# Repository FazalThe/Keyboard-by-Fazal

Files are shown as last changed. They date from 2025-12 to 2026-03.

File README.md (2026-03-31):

# Custom Wireless Mechanical Keyboard (Pico W)
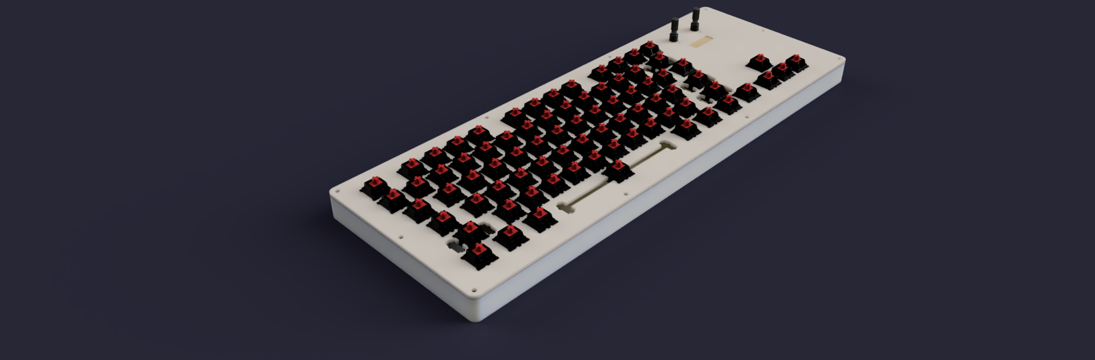
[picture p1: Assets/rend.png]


A custom-designed **wireless mechanical keyboard** built around the **Raspberry Pi Pico W**, featuring a hand-wired key matrix, rotary encoders, OLED display, rechargeable battery support, and a fully custom 3D-printed case.

The **Layout** is custome made by me

---

## 📸 Project Overview

### Top Plate
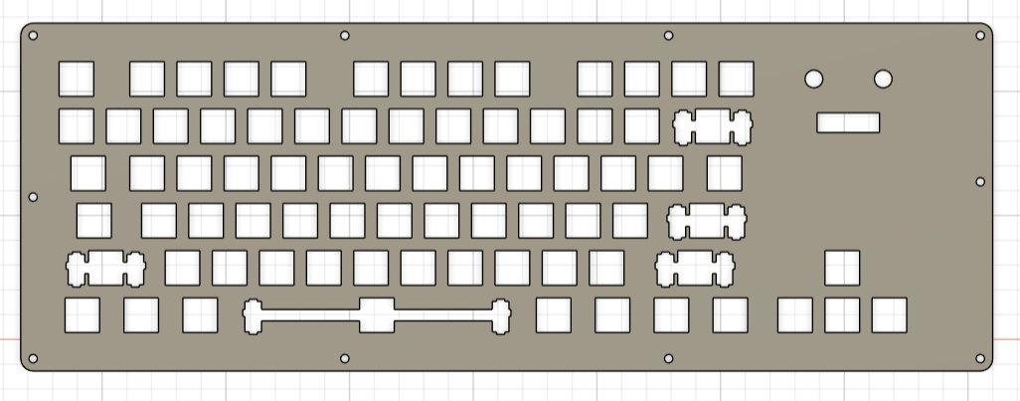
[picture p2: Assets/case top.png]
Case Top


### Case (Bottom Shell)
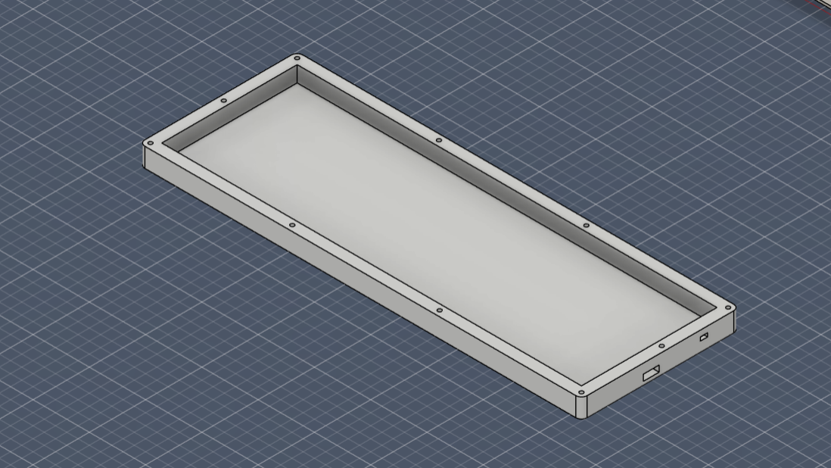
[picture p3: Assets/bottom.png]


### Key Layout
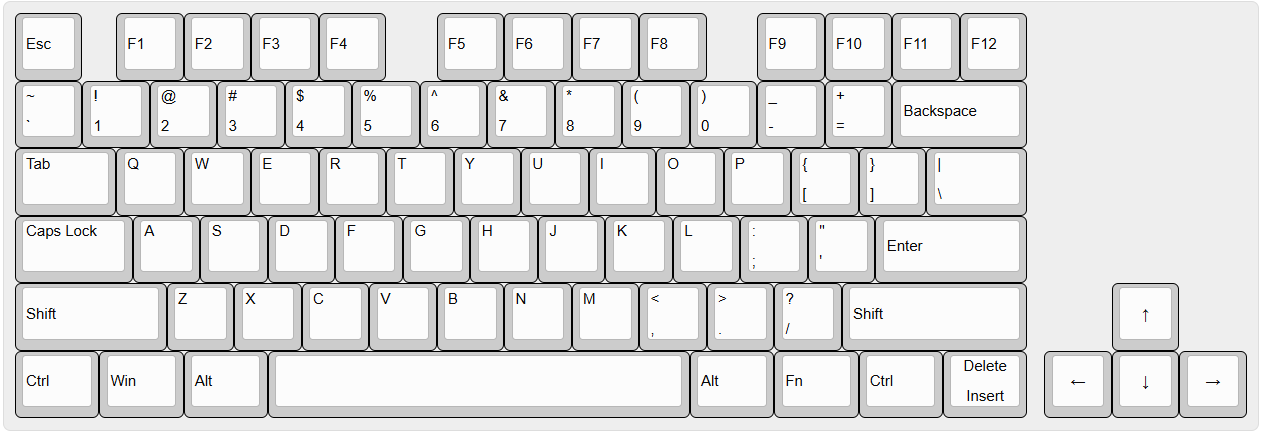
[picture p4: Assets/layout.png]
Layout


### Electrical Schematic
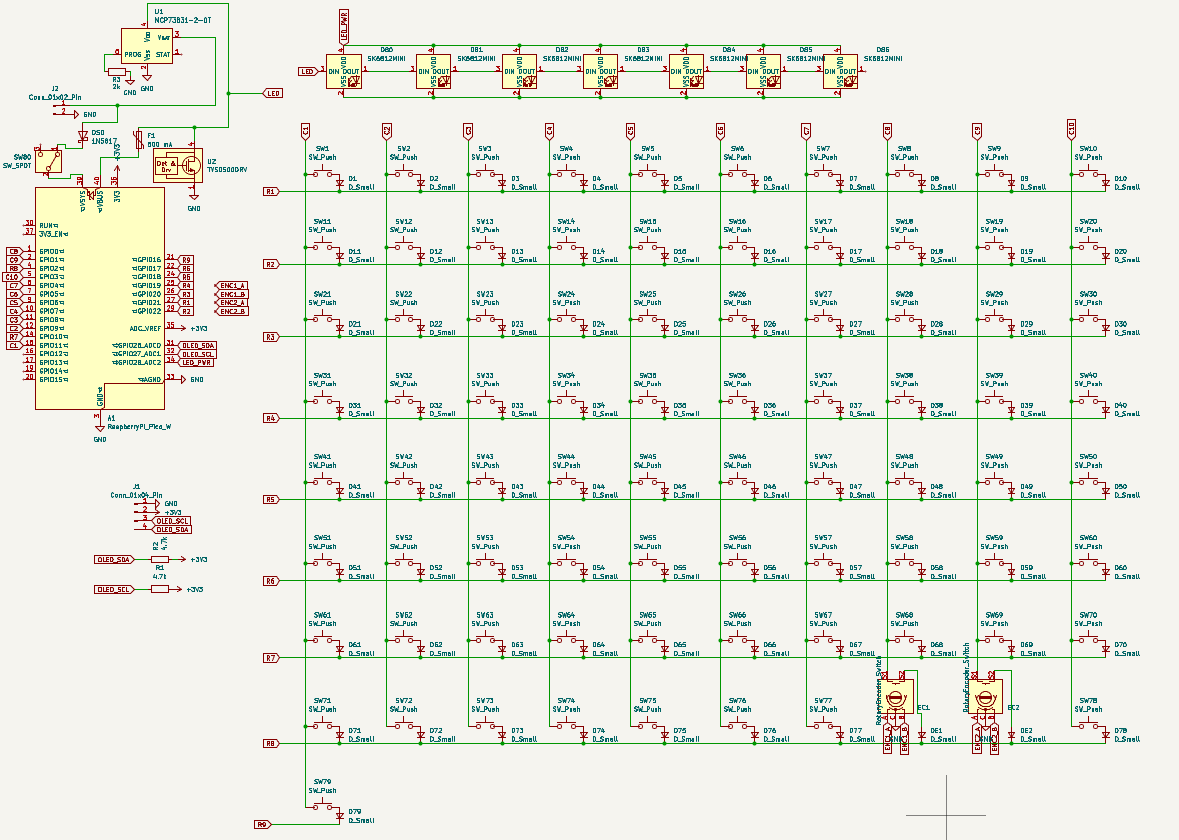
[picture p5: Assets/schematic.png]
Schematic


---

## 🧩 Bill of Materials 
### Core Electronics
- Raspberry Pi Pico W ×1  
- Mechanical key switches ×78  
- Keyboard diodes ×81  
- SK6812 MINI RGB LEDs ×7  
- Rotary encoders ×2  
- 0.91″ OLED display ×1  
- MCP73831 Li-ion charger ×1  
- TVS ESD protection IC ×1  
- Fuse (500 mA) ×1  
- Resistors (4.7 kΩ ×2, 2 kΩ ×1)  

### Power & Connectivity
- Protected Li-Po battery ×1  
- JST 2-pin battery connector ×1  
- USB connector / header ×1  
- SS12F15 slide switch ×1  

### Mechanical & Assembly
- MX keycaps ×78 (look layout for reference)  
- Rotary encoder caps ×2  
- Copper wire (for hand wiring)  
- Solder board / perfboard  
- M3 × 20 mm screws ×8  
- M3 heat-set inserts ×8  

---

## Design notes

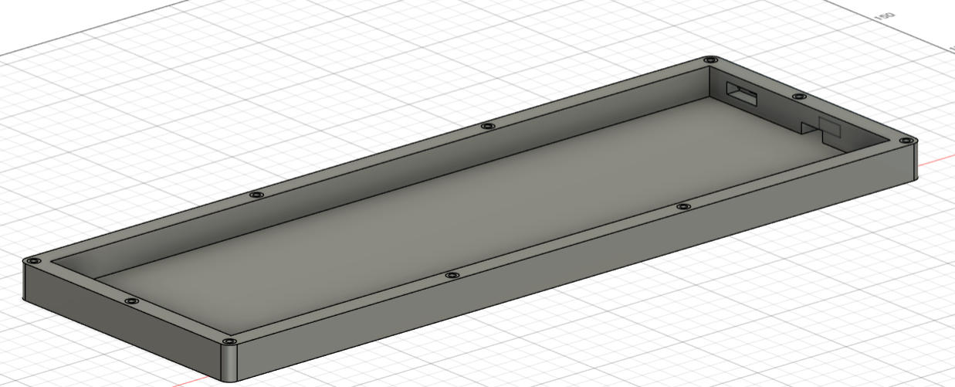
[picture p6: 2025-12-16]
Assets/case.png

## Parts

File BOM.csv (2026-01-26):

Product name | Product link | Price per piece (₹) | Quantity | Total price (₹) | Running total (₹)
Raspberry Pi Pico W | https://robu.in/product/raspberry-pi-pico-w/ | 614.00 | 1 | 614.00 | 614.00
2.2k Ohm 0.5W Metal Film Resistor (Pack of 50) | https://robu.in/product/2-2k-ohm-0-5w-metal-film-resistor-pack-of-50/ | 0.98 | 12 | 11.76 | 625.76
MCP73831T-2ACI/OT Li‑ion Charger IC (SOT‑23‑5) | https://robu.in/product/mcp73831t-2aci-ot-microchip-battery-charger-for-1-cell-of-li-ion-li-pol-battery-6v-input-4-2v-500ma-charge-sot-23-5/ | 89.00 | 1 | 89.00 | 714.76
1N5817 Schottky Rectifier 20V 1A DO‑41 | https://robu.in/product/1-month-warranty-1000/ | 9.00 | 5 | 45.00 | 759.76
0.91″ Monochrome OLED Display Panel Blue 14‑pin | https://robu.in/product/0-91-inch-monochrome-oled-display-panel-blue-14pin-2/ | 106.00 | 1 | 106.00 | 865.76
RXEF050 PTC Resettable Fuse 72V 500 mA (Radial) | https://robu.in/product/70-065-63-0-5a-siba-70-065-63-0-5a-fuse-cartridge-fast-acting-500-ma-500-v-6-3mm-x-32mm-1-4-x-1-1-4/ | 14.00 | 3 | 42.00 | 907.76
Electronic Spices 50Pcs 4.7KΩ 1/2W Resistors | https://www.amazon.in/gp/product/B0BDTXKCM3/ref=ox_sc_act_title_1 | 80.00 | 1 | 80.00 | 987.76
Rechargeable Li‑Po Battery 3.7V 800 mAh | https://www.amazon.in/gp/product/B0DTGSWDGP/ref=ox_sc_act_title_2 | 331.00 | 1 | 331.00 | 1,318.76
TRENDYNEST Plate Mounted Stabilizers 3×2U | https://www.amazon.in/gp/product/B0FRN1CF4Q/ref=ox_sc_act_title_3 | 862.00 | 1 | 862.00 | 2,180.76
Rpi shop M3×16mm CSK Allen Screws (10 pcs) | https://www.amazon.in/gp/product/B07XM7YMC9/ref=ox_sc_act_title_4 | 168.00 | 1 | 168.00 | 2,348.76
Electronic Spices 5 pcs 3×7 cm Universal PCB | https://www.amazon.in/gp/product/B0B8NGQQ9C/ref=ox_sc_act_title_5 | 172.00 | 1 | 172.00 | 2,520.76
100PCS A7 SMD Diode 1A 1000V SOD‑123 (1N4007) | https://www.amazon.in/gp/product/B09VK9966W/ref=ox_sc_act_title_6 | 100.00 | 1 | 100.00 | 2,620.76
CentIoT EC11 10K Rotary Encoder (2 pcs) | https://www.amazon.in/gp/product/B0888RWNM1/ref=ox_sc_act_title_7 | 172.00 | 1 | 172.00 | 2,792.76
Milk & Honey MOA PBT Keycaps | https://curiositycaps.in/products/honey-milk-moa-pbt-keycaps?variant=51748170924313 | 2,200 | 1 | 2,200 | 2,992.76

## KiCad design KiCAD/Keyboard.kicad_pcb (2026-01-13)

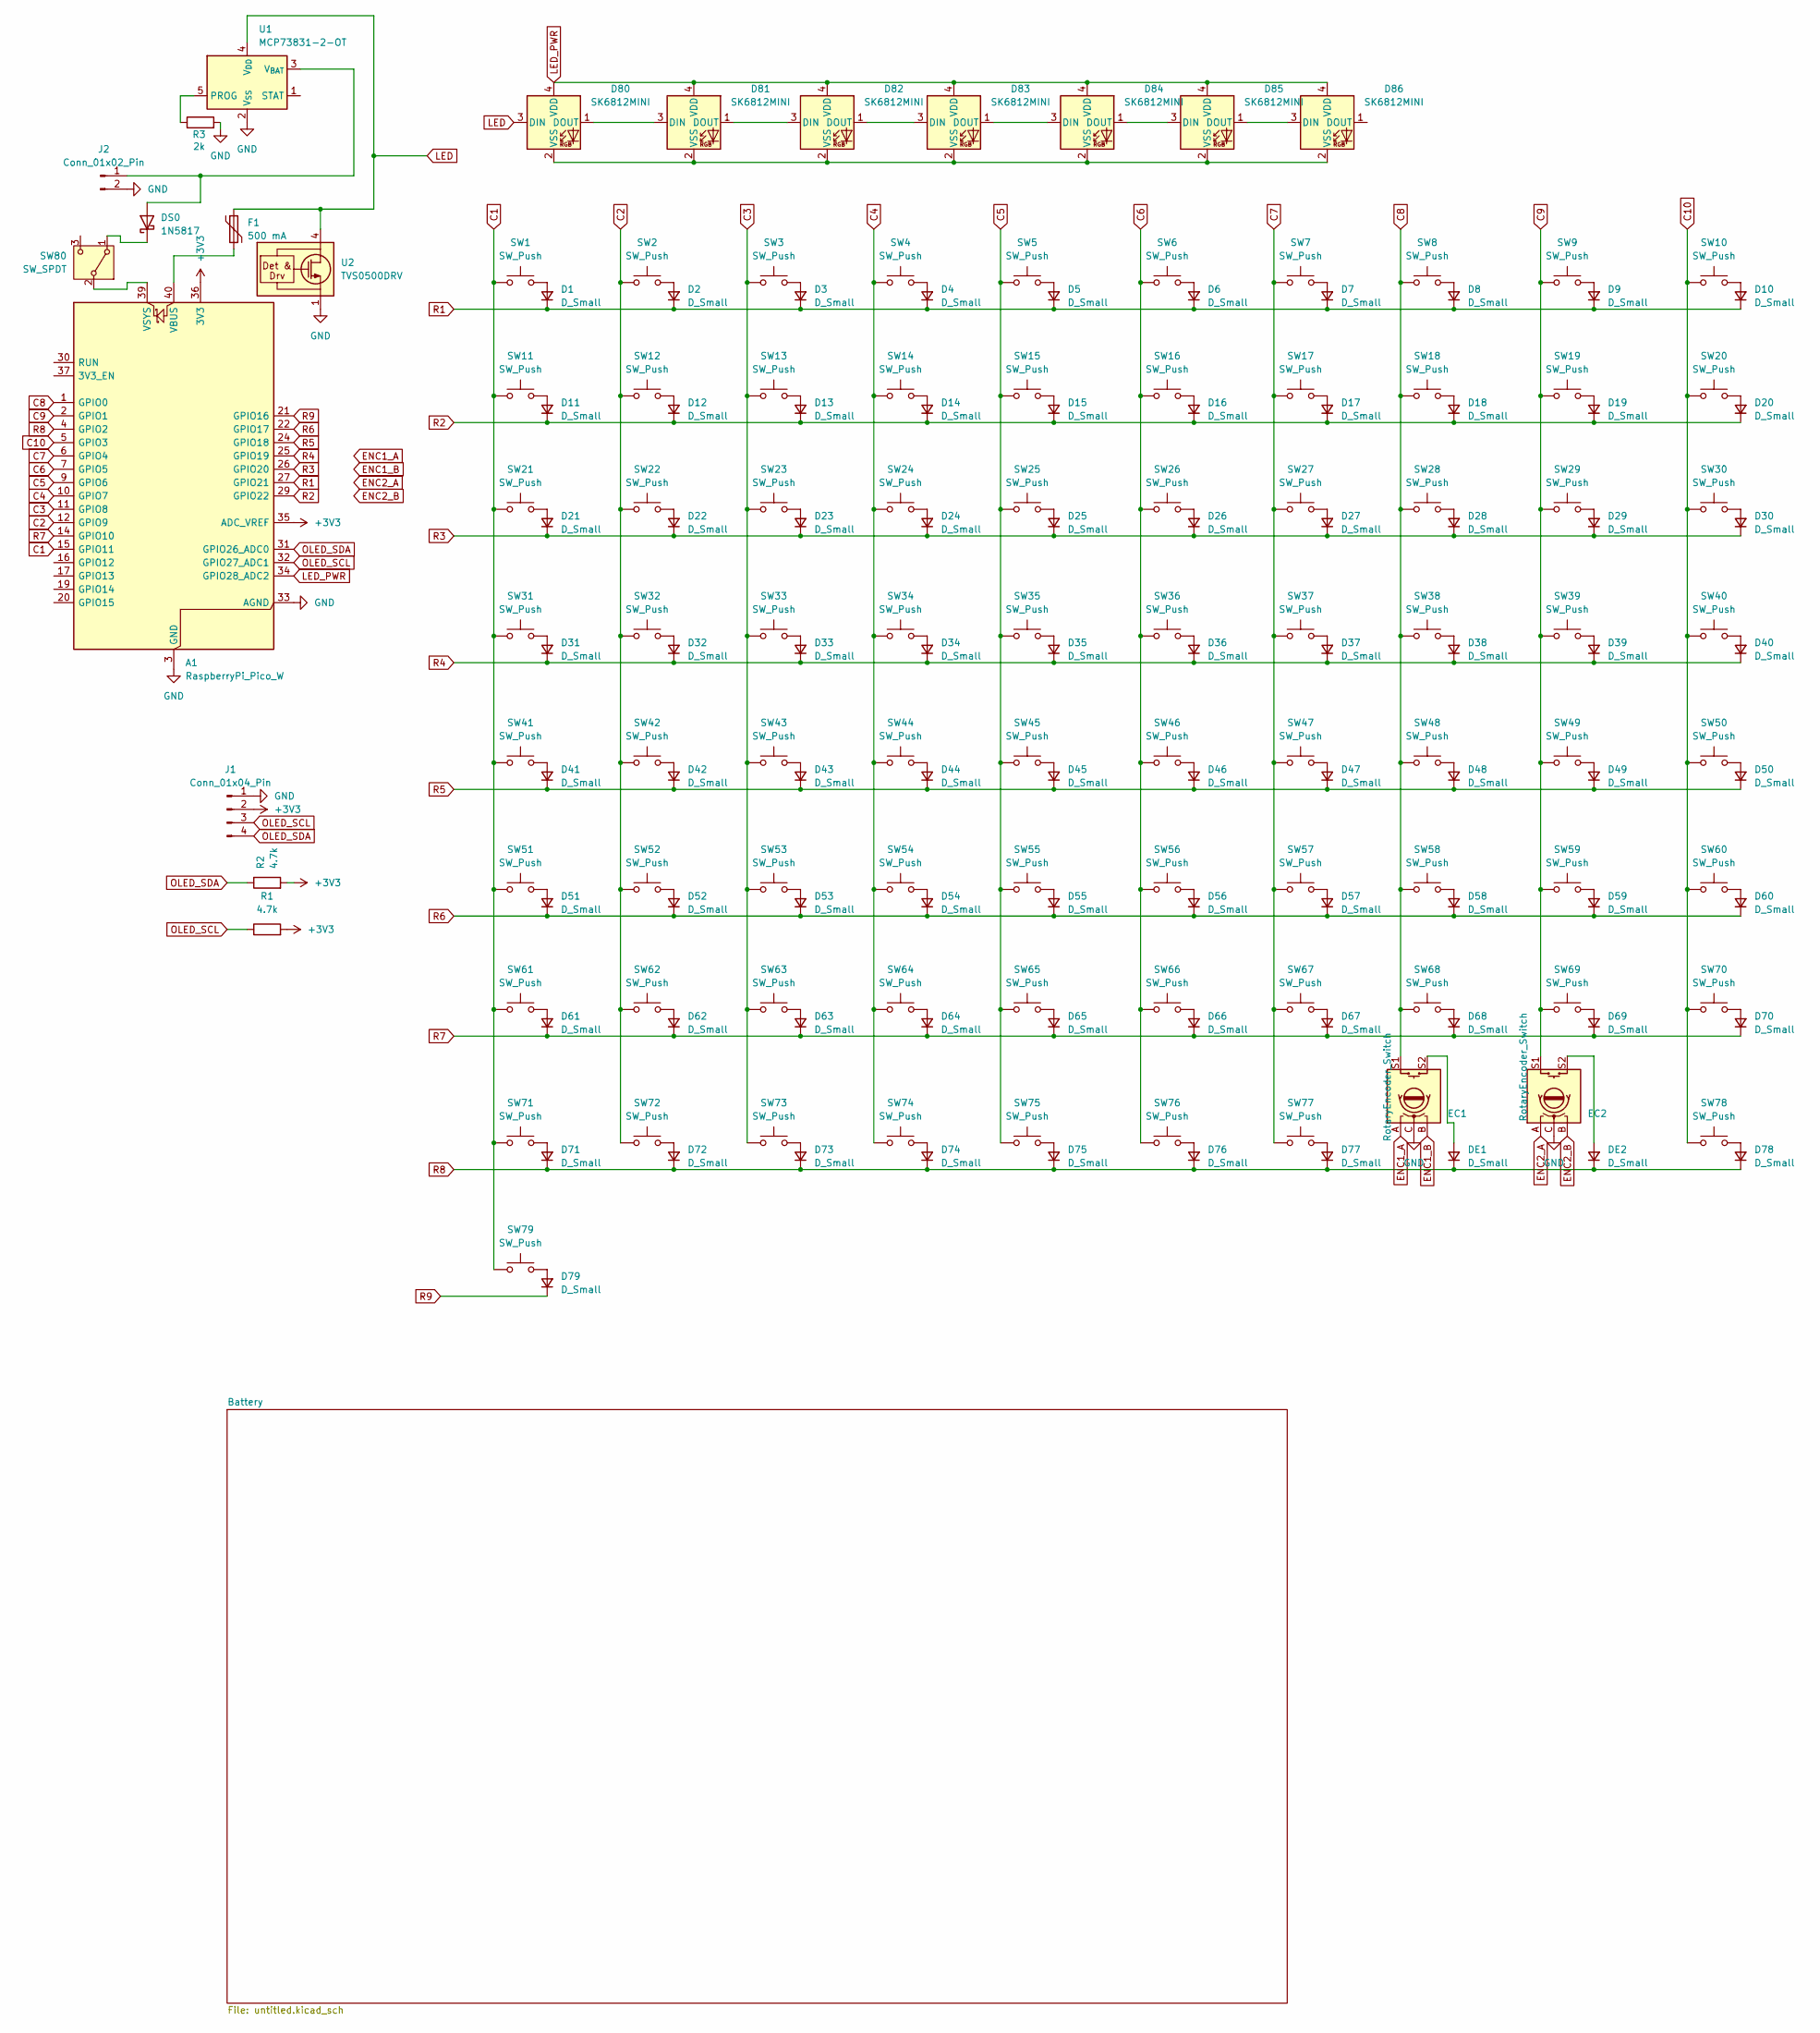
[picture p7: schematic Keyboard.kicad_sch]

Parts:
A1: RaspberryPi_Pico_W; RaspberryPi_Pico_W_SMD_HandSolder
D1, D2, D3, D4, D5, D6, D7, D8, D9, D10, D11, D12, D13, D14, D15, D16, D17, D18, D19, D20, D21, D22, D23, D24, D25, D26, D27, D28, D29, D30, D31, D32, D33, D34, D35, D36, D37, D38, D39, D40, D41, D42, D43, D44, D45, D46, D47, D48, D49, D50, D51, D52, D53, D54, D55, D56, D57, D58, D59, D60, D61, D62, D63, D64, D65, D66, D67, D68, D69, D70, D71, D72, D73, D74, D75, D76, D77, D78, D79: D_Small; D_SOD-123
D80, D81, D82, D83, D84, D85, D86: SK6812MINI; LED_SK6812MINI_PLCC4_3.5x3.5mm_P1.75mm
DE1, DE2: D_Small; D_SOD-123
DS0: 1N5817; D_DO-41_SOD81_P10.16mm_Horizontal
EC1, EC2: RotaryEncoder_Switch; RotaryEncoder_Alps_EC11E-Switch_Vertical_H20mm
F1: 500 mA; Fuse_1206_3216Metric_Pad1.42x1.75mm_HandSolder
J1: Conn_01x04_Pin; PinSocket_1x04_P1.00mm_Vertical_SMD_Pin1Right
J2: Conn_01x02_Pin; JST_PH_S2B-PH-K_1x02_P2.00mm_Horizontal
R1, R2: 4.7k; R_0805_2012Metric_Pad1.20x1.40mm_HandSolder
R3: 2k; R_0805_2012Metric_Pad1.20x1.40mm_HandSolder
SW1, SW2, SW3, SW4, SW5, SW6, SW7, SW8, SW9, SW10, SW11, SW12, SW13, SW14, SW15, SW16, SW17, SW18, SW19, SW20, SW21, SW22, SW23, SW24, SW25, SW26, SW27, SW28, SW29, SW30, SW31, SW32, SW33, SW34, SW35, SW36, SW37, SW38, SW39, SW40, SW41, SW42, SW43, SW44, SW45, SW46, SW47, SW48, SW49, SW50, SW51, SW52, SW53, SW54, SW55, SW56, SW57, SW58, SW59, SW60, SW61, SW62, SW63, SW64, SW65, SW66, SW67, SW68, SW69, SW70, SW71, SW72, SW73, SW74, SW75, SW76, SW77, SW78: SW_Push; SW_Cherry_MX_1.00u_PCB
SW79: SW_Push; SW_SPST_PTS645Sx43SMTR92
SW80: SW_SPDT; SW_SPDT_PCM12
U1: MCP73831-2-OT; SOT-23-5
U2: TVS0500DRV; WSON-6-1EP_2x2mm_P0.65mm_EP1x1.6mm

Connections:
+3V3: A1.35 (ADC_VREF), A1.36 (3V3), J1.2, R1.2, R2.2
C1: A1.15 (GPIO11), SW1.1, SW11.1, SW21.1, SW31.1, SW41.1, SW51.1, SW61.1, SW71.1, SW79.1
C2: A1.12 (GPIO9), SW2.1, SW12.1, SW22.1, SW32.1, SW42.1, SW52.1, SW62.1, SW72.1
C3: A1.11 (GPIO8), SW3.1, SW13.1, SW23.1, SW33.1, SW43.1, SW53.1, SW63.1, SW73.1
C4: A1.10 (GPIO7), SW4.1, SW14.1, SW24.1, SW34.1, SW44.1, SW54.1, SW64.1, SW74.1
C5: A1.9 (GPIO6), SW5.1, SW15.1, SW25.1, SW35.1, SW45.1, SW55.1, SW65.1, SW75.1
C6: A1.7 (GPIO5), SW6.1, SW16.1, SW26.1, SW36.1, SW46.1, SW56.1, SW66.1, SW76.1
C7: A1.6 (GPIO4), SW7.1, SW17.1, SW27.1, SW37.1, SW47.1, SW57.1, SW67.1, SW77.1
C8: A1.1 (GPIO0), EC1.S1, SW8.1, SW18.1, SW28.1, SW38.1, SW48.1, SW58.1, SW68.1
C9: A1.2 (GPIO1), EC2.S1, SW9.1, SW19.1, SW29.1, SW39.1, SW49.1, SW59.1, SW69.1
C10: A1.5 (GPIO3), SW10.1, SW20.1, SW30.1, SW40.1, SW50.1, SW60.1, SW70.1, SW78.1
ENC1_A: EC1.A
ENC1_B: EC1.B
ENC2_A: EC2.A
ENC2_B: EC2.B
GND: A1.3 (GND), A1.8 (GND), A1.13 (GND), A1.18 (GND), A1.23 (GND), A1.28 (GND), A1.33 (AGND), A1.38 (GND), EC1.C, EC2.C, J1.1, J2.2, R3.2, U1.2 (V_{SS}), U2.1 (GND), U2.2 (GND), U2.3 (GND), U2.7 (GND)
unnamed: A1.40 (VBUS), F1.2
unnamed: A1.39 (VSYS), SW80.2 (B)
unnamed: D1.2 (A), SW1.2
unnamed: D2.2 (A), SW2.2
unnamed: D3.2 (A), SW3.2
unnamed: D4.2 (A), SW4.2
unnamed: D5.2 (A), SW5.2
unnamed: D6.2 (A), SW6.2
unnamed: D7.2 (A), SW7.2
unnamed: D8.2 (A), SW8.2
unnamed: D9.2 (A), SW9.2
unnamed: D10.2 (A), SW10.2
unnamed: D11.2 (A), SW11.2
unnamed: D12.2 (A), SW12.2
unnamed: D13.2 (A), SW13.2
unnamed: D14.2 (A), SW14.2
unnamed: D15.2 (A), SW15.2
unnamed: D16.2 (A), SW16.2
unnamed: D17.2 (A), SW17.2
unnamed: D18.2 (A), SW18.2
unnamed: D19.2 (A), SW19.2
unnamed: D20.2 (A), SW20.2
unnamed: D21.2 (A), SW21.2
unnamed: D22.2 (A), SW22.2
unnamed: D23.2 (A), SW23.2
unnamed: D24.2 (A), SW24.2
unnamed: D25.2 (A), SW25.2
unnamed: D26.2 (A), SW26.2
unnamed: D27.2 (A), SW27.2
unnamed: D28.2 (A), SW28.2
unnamed: D29.2 (A), SW29.2
unnamed: D30.2 (A), SW30.2
unnamed: D31.2 (A), SW31.2
unnamed: D32.2 (A), SW32.2
unnamed: D33.2 (A), SW33.2
unnamed: D34.2 (A), SW34.2
unnamed: D35.2 (A), SW35.2
unnamed: D36.2 (A), SW36.2
unnamed: D37.2 (A), SW37.2
unnamed: D38.2 (A), SW38.2
unnamed: D39.2 (A), SW39.2
unnamed: D40.2 (A), SW40.2
unnamed: D41.2 (A), SW41.2
unnamed: D42.2 (A), SW42.2
unnamed: D43.2 (A), SW43.2
unnamed: D44.2 (A), SW44.2
unnamed: D45.2 (A), SW45.2
unnamed: D46.2 (A), SW46.2
unnamed: D47.2 (A), SW47.2
unnamed: D48.2 (A), SW48.2
unnamed: D49.2 (A), SW49.2
unnamed: D50.2 (A), SW50.2
unnamed: D51.2 (A), SW51.2
unnamed: D52.2 (A), SW52.2
unnamed: D53.2 (A), SW53.2
unnamed: D54.2 (A), SW54.2
unnamed: D55.2 (A), SW55.2
unnamed: D56.2 (A), SW56.2
unnamed: D57.2 (A), SW57.2
unnamed: D58.2 (A), SW58.2
unnamed: D59.2 (A), SW59.2
unnamed: D60.2 (A), SW60.2
unnamed: D61.2 (A), SW61.2
unnamed: D62.2 (A), SW62.2
unnamed: D63.2 (A), SW63.2
unnamed: D64.2 (A), SW64.2
unnamed: D65.2 (A), SW65.2
unnamed: D66.2 (A), SW66.2
unnamed: D67.2 (A), SW67.2
unnamed: D68.2 (A), SW68.2
unnamed: D69.2 (A), SW69.2
unnamed: D70.2 (A), SW70.2
unnamed: D71.2 (A), SW71.2
unnamed: D72.2 (A), SW72.2
unnamed: D73.2 (A), SW73.2
unnamed: D74.2 (A), SW74.2
unnamed: D75.2 (A), SW75.2
unnamed: D76.2 (A), SW76.2
unnamed: D77.2 (A), SW77.2
unnamed: D78.2 (A), SW78.2
unnamed: D79.2 (A), SW79.2
unnamed: D80.1 (DOUT), D81.3 (DIN)
unnamed: D80.2 (VSS), D81.2 (VSS), D82.2 (VSS), D83.2 (VSS), D84.2 (VSS), D85.2 (VSS), D86.2 (VSS)
unnamed: A1.34 (GPIO28_ADC2), D80.4 (VDD), D81.4 (VDD), D82.4 (VDD), D83.4 (VDD), D84.4 (VDD), D85.4 (VDD), D86.4 (VDD)
unnamed: D81.1 (DOUT), D82.3 (DIN)
unnamed: D82.1 (DOUT), D83.3 (DIN)
unnamed: D83.1 (DOUT), D84.3 (DIN)
unnamed: D84.1 (DOUT), D85.3 (DIN)
unnamed: D85.1 (DOUT), D86.3 (DIN)
unnamed: DE1.2 (A), EC1.S2
unnamed: DE2.2 (A), EC2.S2
unnamed: DS0.2 (A), J2.1, U1.3 (V_{BAT})
unnamed: DS0.1 (K), SW80.1 (A)
unnamed: R3.1, U1.5 (PROG)
unnamed: D80.3 (DIN), F1.1, U1.4 (V_{DD}), U2.4 (IN), U2.5 (IN), U2.6 (IN)
OLED_SCL: A1.32 (GPIO27_ADC1), J1.3, R1.1
OLED_SDA: A1.31 (GPIO26_ADC0), J1.4, R2.1
R1: A1.27 (GPIO21), D1.1 (K), D2.1 (K), D3.1 (K), D4.1 (K), D5.1 (K), D6.1 (K), D7.1 (K), D8.1 (K), D9.1 (K), D10.1 (K)
R2: A1.29 (GPIO22), D11.1 (K), D12.1 (K), D13.1 (K), D14.1 (K), D15.1 (K), D16.1 (K), D17.1 (K), D18.1 (K), D19.1 (K), D20.1 (K)
R3: A1.26 (GPIO20), D21.1 (K), D22.1 (K), D23.1 (K), D24.1 (K), D25.1 (K), D26.1 (K), D27.1 (K), D28.1 (K), D29.1 (K), D30.1 (K)
R4: A1.25 (GPIO19), D31.1 (K), D32.1 (K), D33.1 (K), D34.1 (K), D35.1 (K), D36.1 (K), D37.1 (K), D38.1 (K), D39.1 (K), D40.1 (K)
R5: A1.24 (GPIO18), D41.1 (K), D42.1 (K), D43.1 (K), D44.1 (K), D45.1 (K), D46.1 (K), D47.1 (K), D48.1 (K), D49.1 (K), D50.1 (K)
R6: A1.22 (GPIO17), D51.1 (K), D52.1 (K), D53.1 (K), D54.1 (K), D55.1 (K), D56.1 (K), D57.1 (K), D58.1 (K), D59.1 (K), D60.1 (K)
R7: A1.14 (GPIO10), D61.1 (K), D62.1 (K), D63.1 (K), D64.1 (K), D65.1 (K), D66.1 (K), D67.1 (K), D68.1 (K), D69.1 (K), D70.1 (K)
R8: A1.4 (GPIO2), D71.1 (K), D72.1 (K), D73.1 (K), D74.1 (K), D75.1 (K), D76.1 (K), D77.1 (K), D78.1 (K), DE1.1 (K), DE2.1 (K)
R9: A1.21 (GPIO16), D79.1 (K)

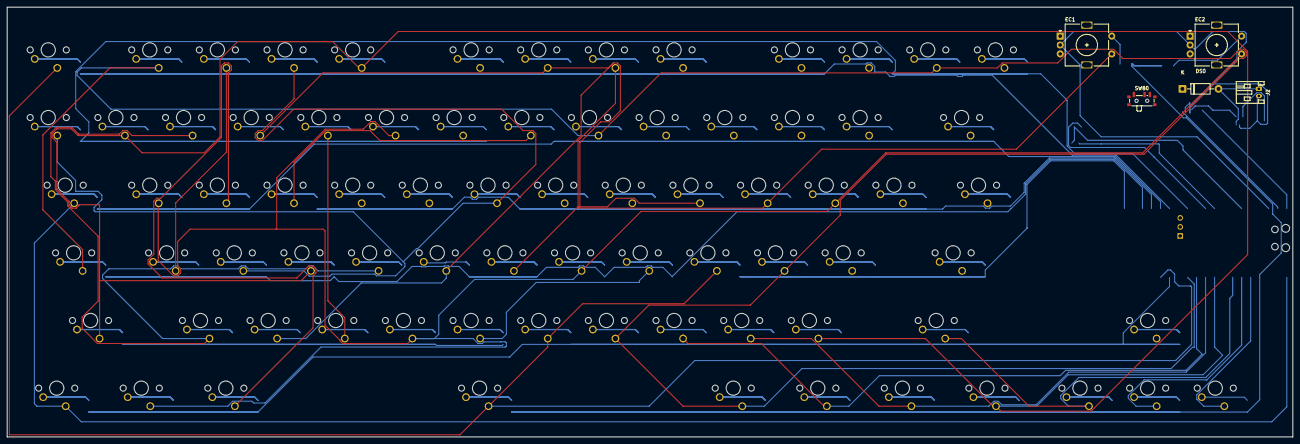
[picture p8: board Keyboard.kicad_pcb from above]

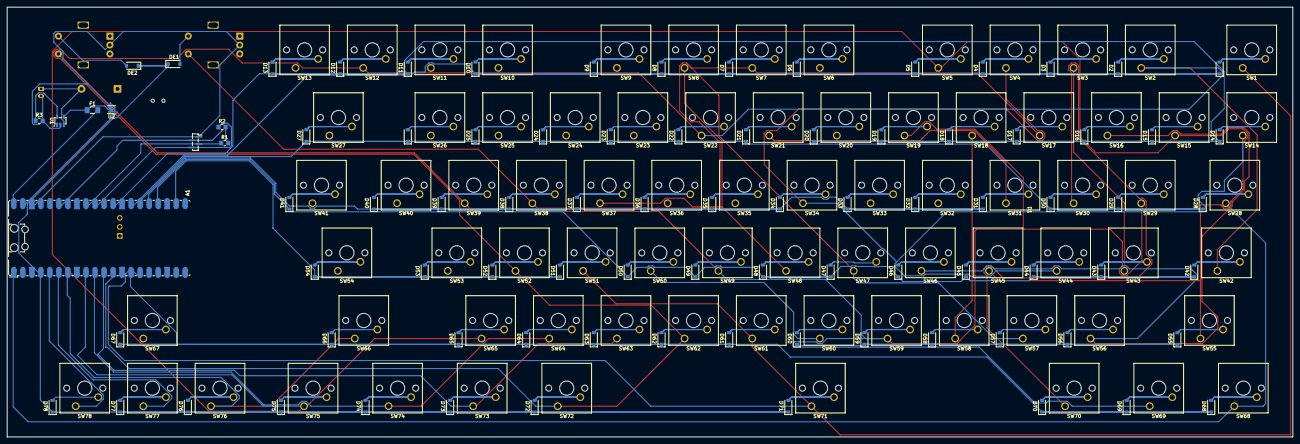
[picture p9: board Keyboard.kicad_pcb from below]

Board: 2 copper layers, 362.0 x 121.0 mm, 171 parts (166 on the bottom side), 108 nets.

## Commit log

2025-12-16 Revise README with detailed project information
    Expanded project description and added detailed sections including project overview, bill of materials, assembly notes, and repository structure.
2026-02-05 Update keyboard description and remove assembly notes
    Removed assembly notes section and updated keyboard description.
2026-03-31 Update images and revise Bill of Materials section
